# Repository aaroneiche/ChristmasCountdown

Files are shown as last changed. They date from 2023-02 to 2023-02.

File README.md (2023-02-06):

# Christmas Countdown

Christmas Countdown is a Christmas Ornament that counts down to Christmas day (or really any day) in Binary. Using two rows of LEDs, it displays the Days & Hours and then the Minutes & seconds remaining until Christmas Day. If you want to learn about how I approached developing it, and how many times I got it wrong, you can read my writeup of [the whole adventure here](https://aaroneiche.com/2023/02/05/christmas-countdown/) 



The heart of the circuit is an ESP32-C3-Mini-1. It drives fourteen SK6812 LEDs that display the time, as well as an indicator of the current mode. The time is kept by a PCF85363 with a battery backup . The ornament runs off of 5v, and requires about 1A with the LEDs running at full brightness (I do not recommend this, these LEDs will melt your face off) 

### Setting the time.

To set the ornament, press and hold the left button for 3 seconds and release. On the bottom row it shows what you're setting (year, month, day, hour, minute, second) and the top row displays the current value. There are 12 settings in all, 6 for the current date/time, and 6 for the target date/time. You can advance to the next value to set by pressing the left button. You can increase the value by pressing the right button. The value will return to zero (or one) after the maximum value has been reached. You do not need to do any math about timing, just set the current and target dates/times. The default target date is December 25th, 00:00:00 AM. You may wish to set the time to December 25th, 08:00:00 for when you start Christmas with your family. Perhaps you observe Orthodox Christmas and want to set it for January 7th.

When setting the current date/time, the whole bottom row will be lit with the value you're setting flashing on and off.
Here is an example of setting the current year (22 - for 2022)

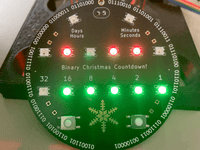
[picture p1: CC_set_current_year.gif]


When setting the target date/time, the whole bottom row will be off with the value you're setting flashing on an off.
Here is an example of setting the target month (12 - for December)

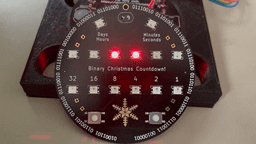
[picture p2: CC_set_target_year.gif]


When you've finished setting the values, press and hold the right button for 3 seconds. The countdown values will appear.

## Clock battery

If power is lost to Christmas Countdown, the RTC will go into battery mode automatically and will continue to count time. The RTC battery runs on very low power mode consuming ~320nA. 

If the battery is removed, some settings will be maintained on Christmas Countdown. The current time will need to be set again.

## Adding to the the software

I wrote most of this software in VSCode with PlatformIO. I programmed the Esp32-C3 using a CP1202 USB->UART adapter, and connecting the DTR and RTS pins. Alternatively, you should be able to put the board in download mode by holding down the "Program" button on the back while pressing and releasing the "Reset" button.

Changes to the firmware should be pretty easy to make. It's all (in)conveniently in a single file. A couple of helpful hints: 

A clock interrupt fires 1024 times a second. This is how the clock, and the various display updates are handled. There are currently events that execute at 1s, 0.5s and 0.25s. Any handler can be added to the `quarterSecondOverflow`, `halfSecondOverflow`, and `secondOverflow` branches in the loop. These are good locations for executing frequent.

The very last execution in the loop is to update the display. This creates a buffer and that is fed to the `displayFromBuffer` method. This should make it easy to set the display to whatever you want. To prevent your LEDs from getting overwritten by other stuff, make sure to pay attention to the other modes that are writing to the display. The easiest way to avoid this is to make your own Display Mode - you can add one about line 50 in the `enum DisplayMode`.

# Hardware

I typically order PCBs with 1oz copper, HASL Lead-Free. The Color isn't super important. I think that Black looks best, and if you're willing to splurge, Gold ENIG looks very nice on the Snowflake on the front.

The Piezo buzzer does not currently do anything. I have run some tests where I can get it to play some simple music. It definitely works, I just haven't done anything with it yet.

Taking advantage of the Interact HTML BOM, there's a component placement page included in this repo (`ibom.html`)

## What about Wifi?!?!

Yes, the onboard chip has support for Wifi. Which means that you could set the time automatically using NTP. And you could change settings on a webpage even! I have written some code to support these features, and when they're polished I will be making them available. For now, Christmas countdown must be programmed using a couple of buttons and your cunning.

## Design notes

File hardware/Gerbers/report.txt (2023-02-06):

Info: Front (top side) placement file: '/Users/aeiche/Documents/Personal/Electronics Projects/ChristmasCountdown2022_1.3/Gerbers/ChristmasCountdown2022-top.pos'.
Info: Component count: 21.
Info: Back (bottom side) placement file: '/Users/aeiche/Documents/Personal/Electronics Projects/ChristmasCountdown2022_1.3/Gerbers/ChristmasCountdown2022-bottom.pos'.
Info: Component count: 58.
Info: Full component count: 79.
Info: File generation successful.

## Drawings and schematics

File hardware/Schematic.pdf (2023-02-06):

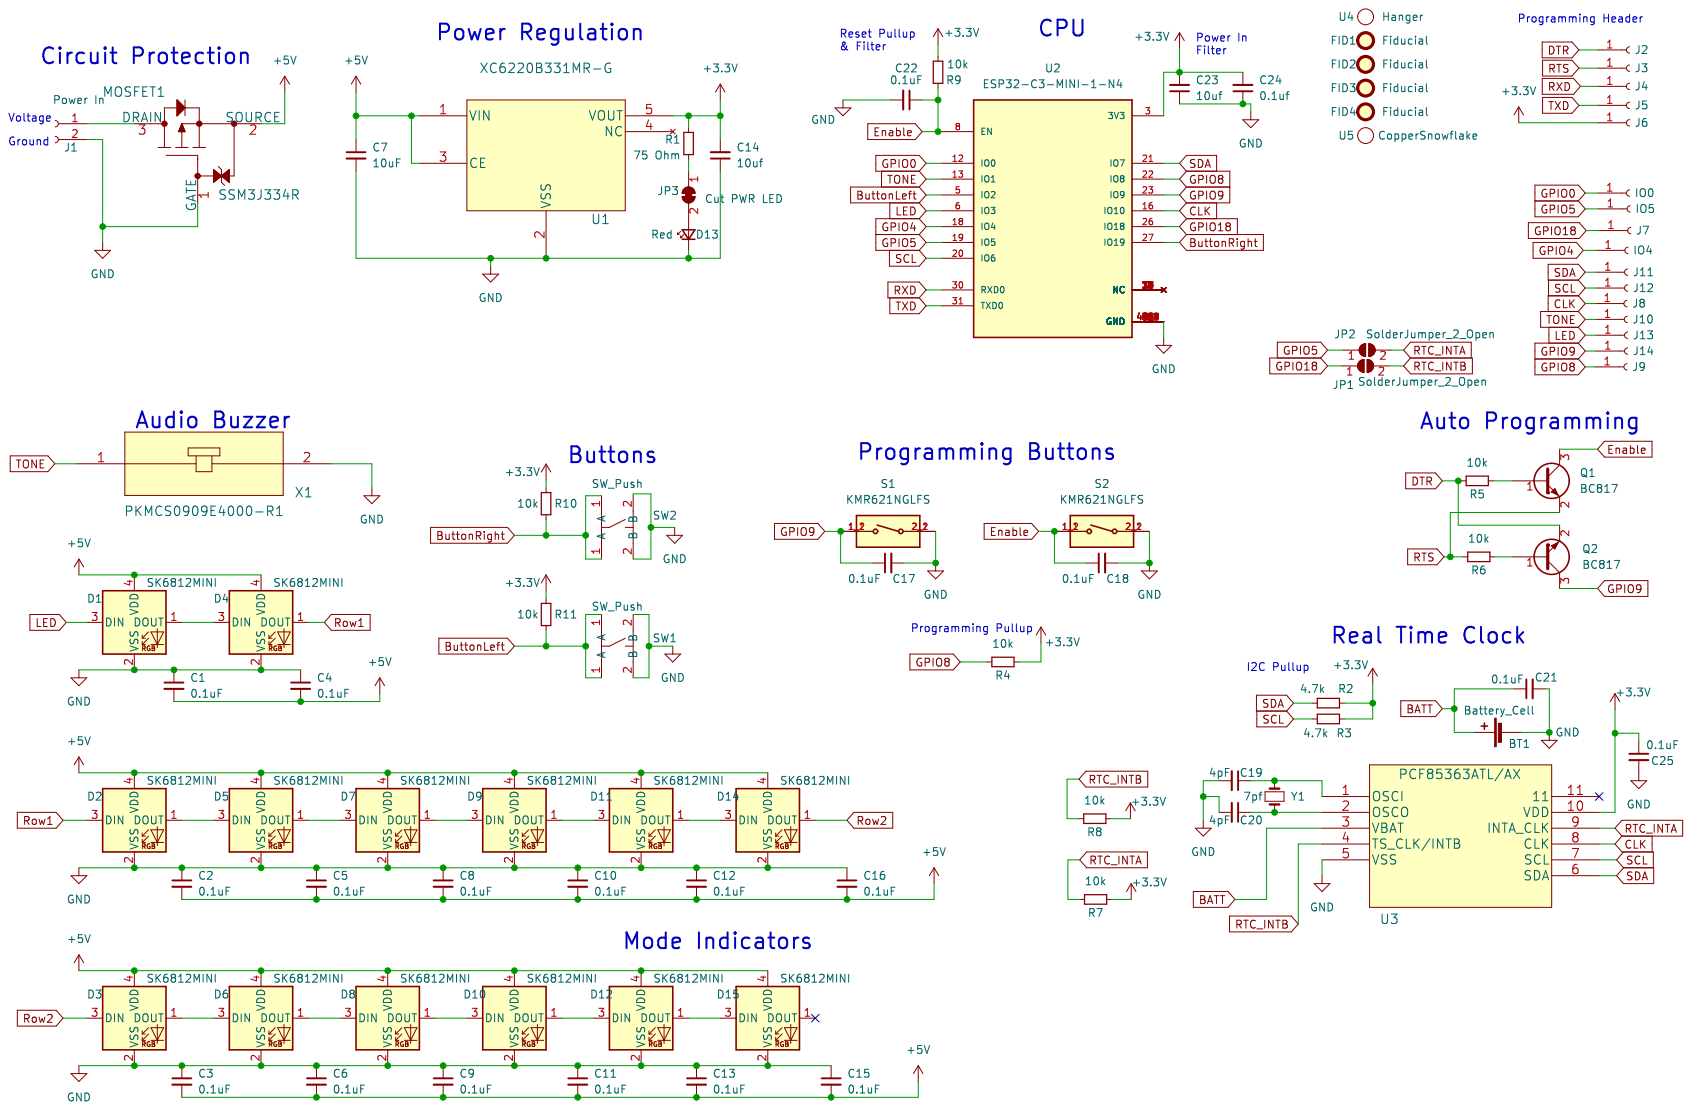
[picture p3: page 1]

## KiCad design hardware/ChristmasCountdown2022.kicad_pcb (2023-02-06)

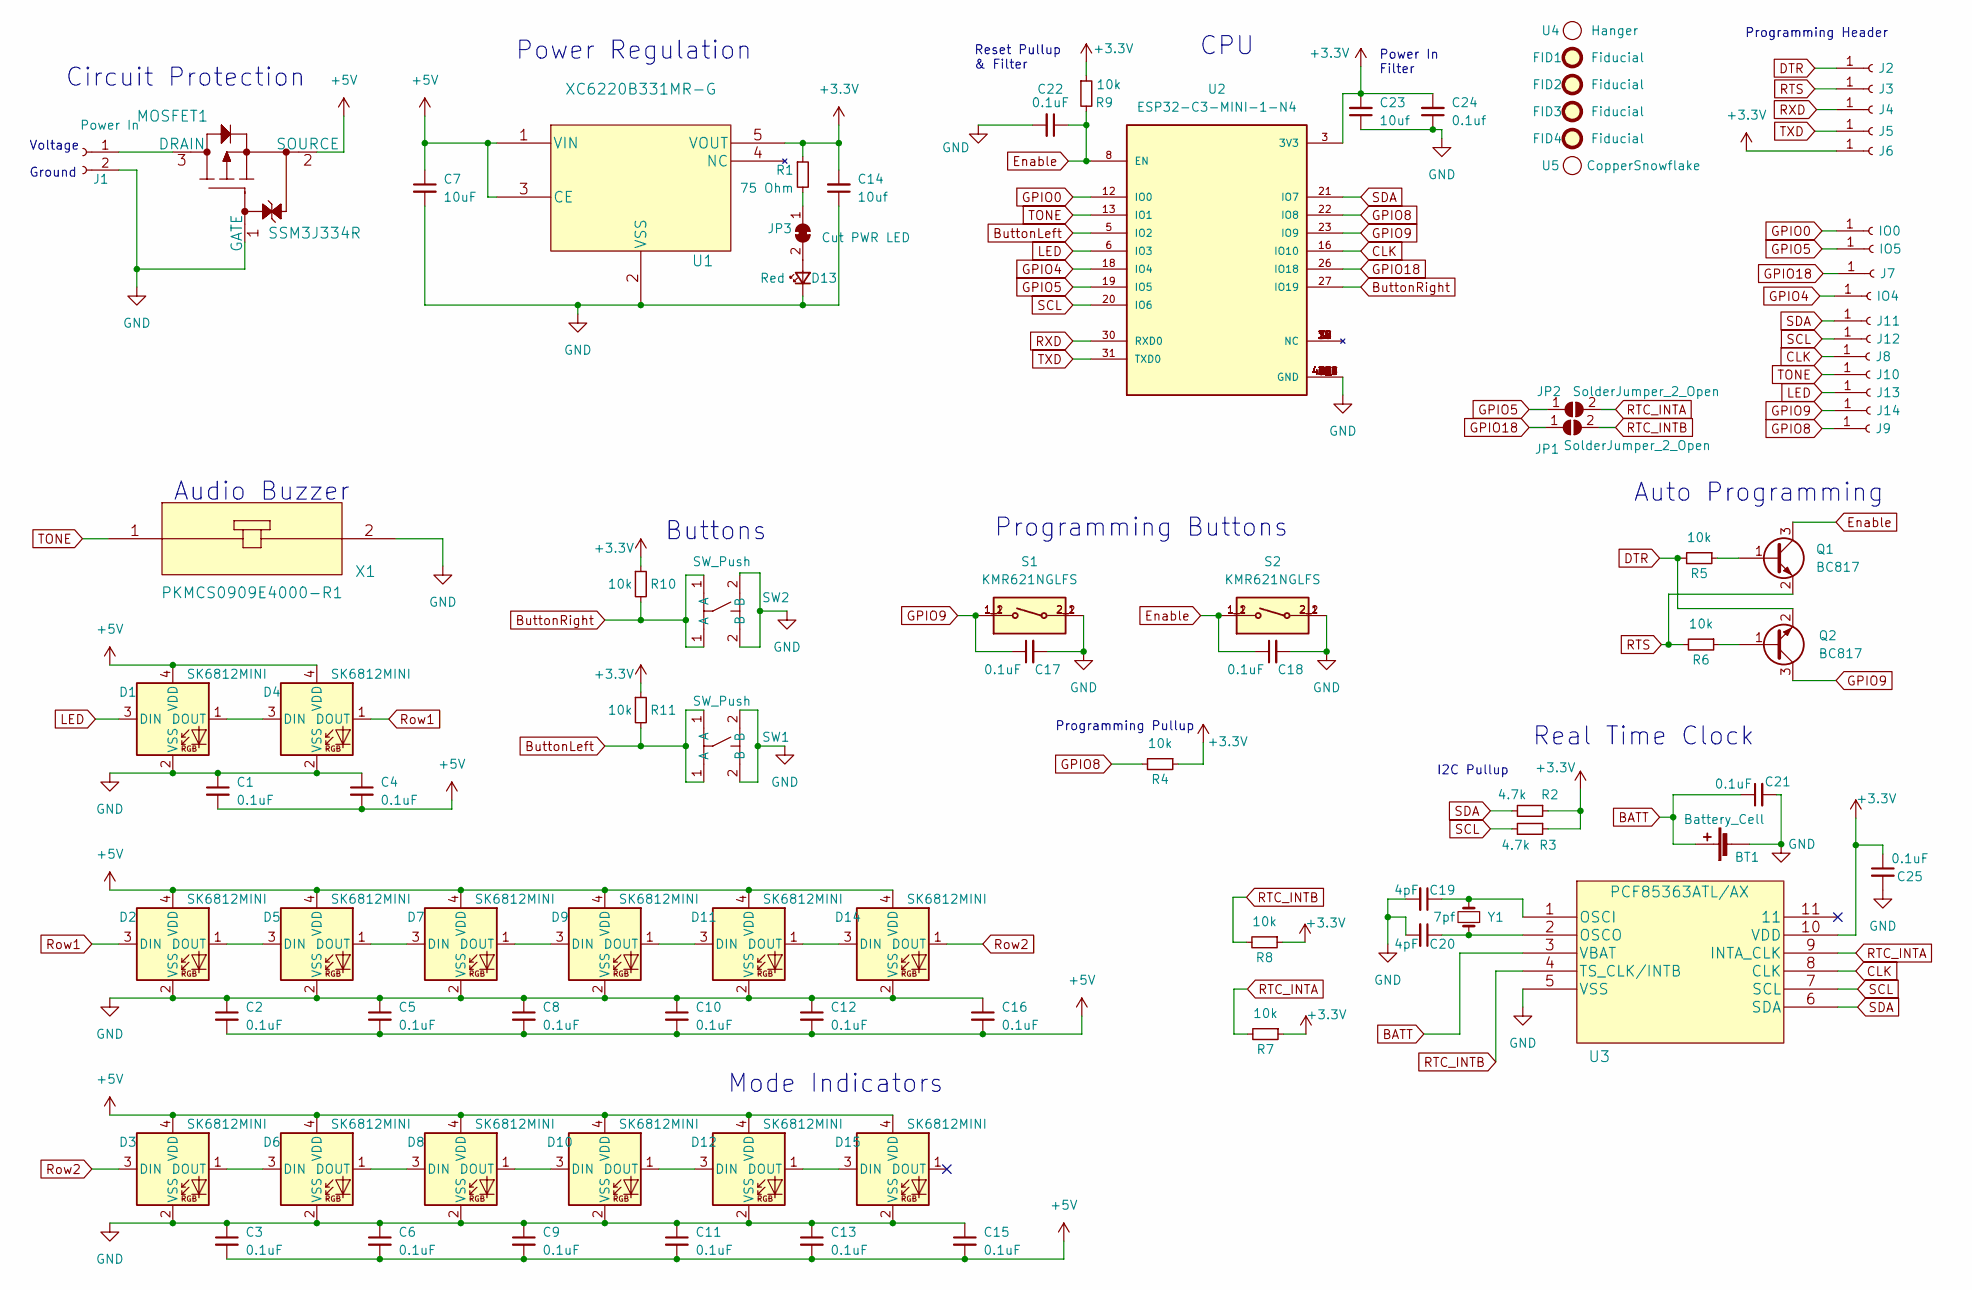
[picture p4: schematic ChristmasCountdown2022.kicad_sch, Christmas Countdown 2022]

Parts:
BT1: Battery_Cell; BatteryHolder_LINX_BAT-HLD-012-SMT
C1, C2, C3, C4, C5, C6, C8, C9, C10, C11, C12, C13, C15, C16, C17, C18, C21, C22, C25: 0.1uF; C_0805_2012Metric
C7: 10uF; C_0805_2012Metric
C14, C23: 10uf; C_0805_2012Metric
C19, C20: 4pF; R_0805_2012Metric
C24: 0.1uf; C_0805_2012Metric
D1, D2, D3, D4, D5, D6, D7, D8, D9, D10, D11, D12, D14, D15: SK6812MINI; LED_SK6812MINI_PLCC4_3.5x3.5mm_P1.75mm
D13: Red; LED_0805_2012Metric
FID1, FID2, FID3, FID4: Fiducial; Fiducial_0.5mm_Mask1mm
IO0: IO0; TestPoint_Pad_D2.0mm
IO4: IO4; TestPoint_Pad_D2.0mm
IO5: IO5; TestPoint_Pad_D2.0mm
J1: Power In; Hand_solderable_1x2
J2, J3, J4, J5, J6: Conn_01x01_Female; PinSocket_1x01_P2.54mm_Vertical
J7: IO18; TestPoint_Pad_D2.0mm
J8: CLK; PinSocket_1x01_P2.54mm_Vertical
J9: IO8; TestPoint_Pad_D2.0mm
J10: TONE; PinSocket_1x01_P2.54mm_Vertical
J11: SDA; TestPoint_Pad_D2.0mm
J12: SCL; TestPoint_Pad_D2.0mm
J13: LED; PinSocket_1x01_P2.54mm_Vertical
J14: IO9; TestPoint_Pad_D2.0mm
JP1, JP2: SolderJumper_2_Open; SolderJumper-2_P1.3mm_Open_RoundedPad1.0x1.5mm
JP3: Cut PWR LED; SolderJumper-2_P1.3mm_Bridged_RoundedPad1.0x1.5mm
MOSFET1: SSM3J334R
Q1, Q2: BC817; SOT-23
R1: 75 Ohm; R_0805_2012Metric
R2, R3: 4.7k; R_0805_2012Metric
R4, R5, R6, R7, R8, R9, R10, R11: 10k; R_0805_2012Metric
S1, S2: KMR621NGLFS; SW_KMR621NGLFS; PARTREV N/A
SW1, SW2: SW_Push; EVQQ2B03W; MFG_Part_number EVQ-Q2F02W
U1: XC6220B331MR-G
U2: ESP32-C3-MINI-1-N4; XCVR_ESP32-C3-MINI-1-N4; PARTREV v1.0
U3: PCF85363ATL/AX; PCF85363ATL_AX
U4: Hanger
U5: CopperSnowflake; CopperSnowflakeGraphic
X1: PKMCS0909E4000-R1
Y1: 7pf; CM8V-T1A-Crystal

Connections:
+3.3V: C14.2, C23.2, C24.2, C25.1, J6.1, R1.1, R2.1, R3.1, R4.1, R7.1, R8.1, R9.1, R10.1, R11.1, U1.5 (VOUT), U2.3 (3V3), U3.10 (VDD)
+5V: C1.2, C2.2, C3.2, C4.2, C5.2, C6.2, C7.1, C8.2, C9.2, C10.2, C11.2, C12.2, C13.2, C15.2, C16.2, D1.4 (VDD), D2.4 (VDD), D3.4 (VDD), D4.4 (VDD), D5.4 (VDD), D6.4 (VDD), D7.4 (VDD), D8.4 (VDD), D9.4 (VDD), D10.4 (VDD), D11.4 (VDD), D12.4 (VDD), D14.4 (VDD), D15.4 (VDD), MOSFET1.2 (SOURCE), U1.1 (VIN), U1.3 (CE)
BATT: BT1.1 (+), C21.1, U3.3 (VBAT)
ButtonLeft: R11.2, SW1.1 (A), U2.5 (IO2)
ButtonRight: R10.2, SW2.1 (A), U2.27 (IO19)
CLK: J8.1, U2.16 (IO10), U3.8 (CLK)
DTR: J2.1, Q2.2 (E), R5.2
Enable: C18.1, C22.1, Q1.3 (C), R9.2, S2.1_1, S2.1_2, U2.8 (EN)
GND: BT1.2 (-), C1.1, C2.1, C3.1, C4.1, C5.1, C6.1, C7.2, C8.1, C9.1, C10.1, C11.1, C12.1, C13.1, C14.1, C15.1, C16.1, C17.2, C18.2, C19.2, C20.2, C21.2, C22.2, C23.1, C24.1, C25.2, D1.2 (VSS), D2.2 (VSS), D3.2 (VSS), D4.2 (VSS), D5.2 (VSS), D6.2 (VSS), D7.2 (VSS), D8.2 (VSS), D9.2 (VSS), D10.2 (VSS), D11.2 (VSS), D12.2 (VSS), D13.1 (K), D14.2 (VSS), D15.2 (VSS), J1.2, MOSFET1.1 (GATE), S1.2_1, S1.2_2, S2.2_1, S2.2_2, SW1.2 (B), SW2.2 (B), U1.2 (VSS), U2.1 (GND), U2.2 (GND), U2.11 (GND), U2.14 (GND), U2.36 (GND), U2.37 (GND), U2.38 (GND), U2.39 (GND), U2.40 (GND), U2.41 (GND), U2.42 (GND), U2.43 (GND), U2.44 (GND), U2.45 (GND), U2.46 (GND), U2.47 (GND), U2.48 (GND), U2.49_1 (GND), U2.49_2 (GND), U2.49_3 (GND), U2.49_4 (GND), U2.49_5 (GND), U2.49_6 (GND), U2.49_7 (GND), U2.49_8 (GND), U2.49_9 (GND), U2.50 (GND), U2.51 (GND), U2.52 (GND), U2.53 (GND), U3.5 (VSS), X1.2
GPIO0: IO0.1, U2.12 (IO0)
GPIO4: IO4.1, U2.18 (IO4)
GPIO5: IO5.1, JP2.1 (A), U2.19 (IO5)
GPIO8: J9.1, R4.2, U2.22 (IO8)
GPIO9: C17.1, J14.1, Q2.3 (C), S1.1_1, S1.1_2, U2.23 (IO9)
GPIO18: J7.1, JP1.1 (A), U2.26 (IO18)
LED: D1.3 (DIN), J13.1, U2.6 (IO3)
unnamed: C19.1, U3.1 (OSCI), Y1.2
unnamed: C20.1, U3.2 (OSCO), Y1.1
unnamed: D1.1 (DOUT), D4.3 (DIN)
unnamed: D2.1 (DOUT), D5.3 (DIN)
unnamed: D3.1 (DOUT), D6.3 (DIN)
unnamed: D5.1 (DOUT), D7.3 (DIN)
unnamed: D6.1 (DOUT), D8.3 (DIN)
unnamed: D7.1 (DOUT), D9.3 (DIN)
unnamed: D10.1 (DOUT), D12.3 (DIN)
unnamed: D8.1 (DOUT), D10.3 (DIN)
unnamed: D11.1 (DOUT), D14.3 (DIN)
unnamed: D9.1 (DOUT), D11.3 (DIN)
unnamed: D12.1 (DOUT), D15.3 (DIN)
unnamed: D13.2 (A), JP3.2 (B)
unnamed: J1.1, MOSFET1.3 (DRAIN)
unnamed: JP3.1 (A), R1.2
unnamed: Q1.1 (B), R5.1
unnamed: Q2.1 (B), R6.1
RTC_INTA: JP2.2 (B), R7.2, U3.9 (INTA_CLK)
RTC_INTB: JP1.2 (B), R8.2, U3.4 (TS_CLK/INTB)
RTS: J3.1, Q1.2 (E), R6.2
RXD: J4.1, U2.30 (RXD0)
Row1: D2.3 (DIN), D4.1 (DOUT)
Row2: D3.3 (DIN), D14.1 (DOUT)
SCL: J12.1, R3.2, U2.20 (IO6), U3.7 (SCL)
SDA: J11.1, R2.2, U2.21 (IO7), U3.6 (SDA)
TONE: J10.1, U2.13 (IO1), X1.1
TXD: J5.1, U2.31 (TXD0)

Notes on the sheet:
Auto Programming
Circuit Protection
Power Regulation
CPU
Programming Header
Real Time Clock
Programming Pullup
Mode Indicators
Audio Buzzer
I2C Pullup
Buttons
Voltage
Power In Filter
Ground
Programming Buttons
Reset Pullup & Filter

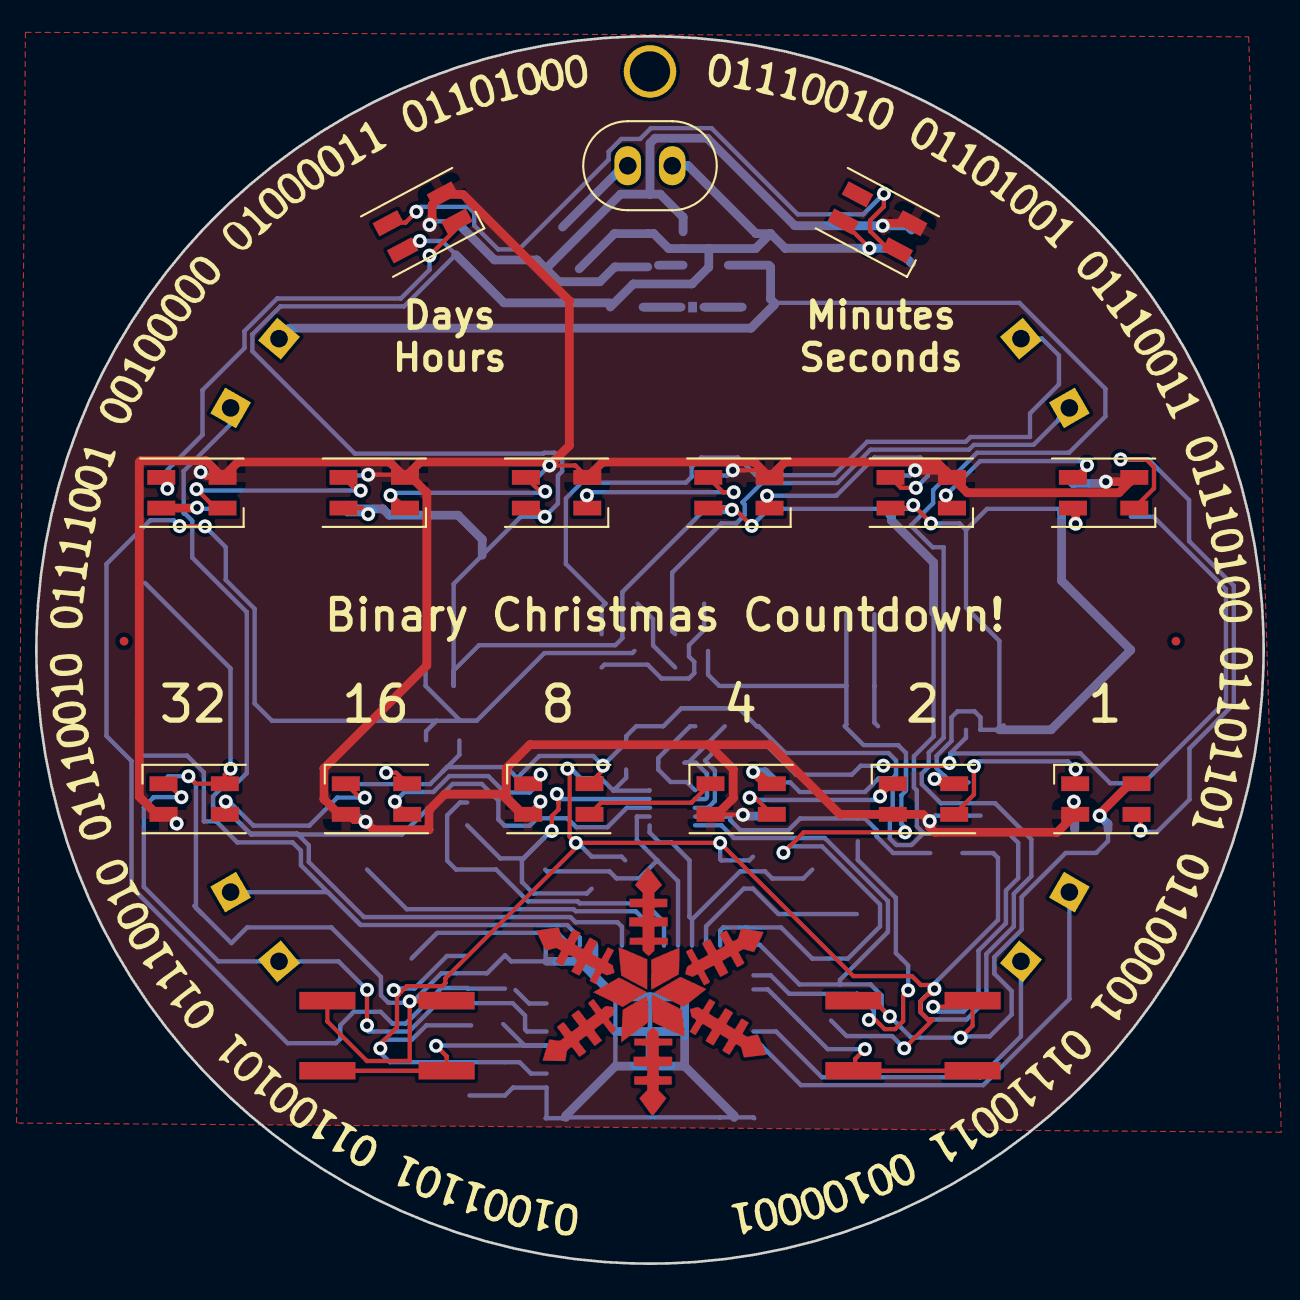
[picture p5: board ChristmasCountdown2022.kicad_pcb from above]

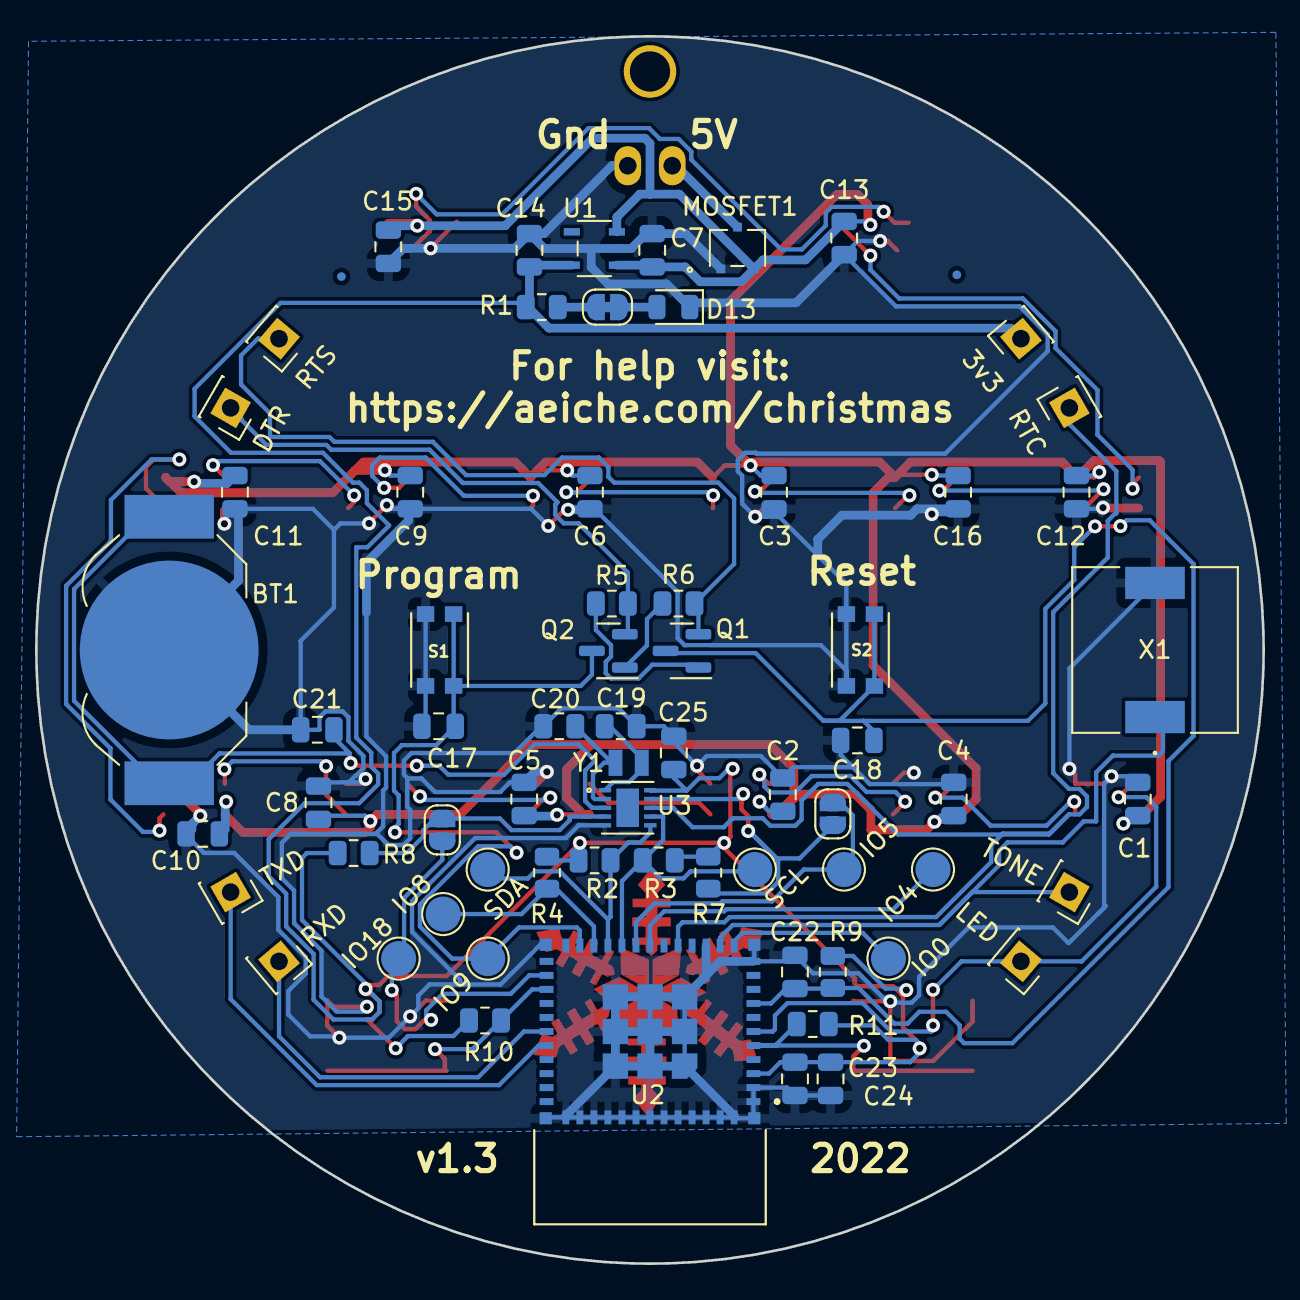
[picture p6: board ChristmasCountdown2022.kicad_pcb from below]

Board: 2 copper layers, 70.0 x 70.0 mm, 90 parts (69 on the bottom side), 44 nets.

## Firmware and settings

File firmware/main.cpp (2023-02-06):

#include <Arduino.h>
#include <Wire.h>
#include <Adafruit_NeoPixel.h>

#include <WiFi.h>

#include <WiFiUdp.h>
#include "NTP.h"

#include "credentials.h"
#include <Bounce2.h>

#include <TimeLib.h>

#include <Preferences.h>

// The I2C address of the RTC.
int address = 0x51;

// The structure that we manage a date in.
struct DateTime
{
  int month;
  int day;
  int hour;
  int minute;
  int second;
};

DateTime remaining;

int secondC = 0;
int halfSecondC = 0;
int quarterSecondC = 0;
int tenthSecondC = 0;

int completeDisplayCounter = 0;
int ledOffset = 0;

int secondOverflowCounter = 0;
int halfsecondOverflowCounter = 0;
int quarterSecondOverflowCounter = 0;

int leftButtonHeldCounter = 0;
int rightButtonHeldCounter = 0;

bool secondOverflow = false;
bool halfSecondOverflow = false;
bool quarterSecondOverflow = false;

//Debounce init.
Bounce bounceRight = Bounce();
Bounce bounceLeft = Bounce();

enum DisplayMode
{
  Day = 1,
  Minute = 2,
  Set = 3,
  Complete = 4
};

DisplayMode currentDisplayMode = Minute;

enum SettingValue
{
  SetDay = 1,
  SetHour = 2,
  SetMinute = 3,
  SetSecond = 4,
  SetMonth = 5,
  SetYear = 6,
  SetTargetDay = 7,
  SetTargetHour = 8,
  SetTargetMinute = 9,
  SetTargetSecond = 10,
  SetTargetMonth = 11,
  SetTargetYear = 12
};

SettingValue currentSettingValue = SetYear;

// counting occurs every 1/4 sec, so 48 * .25 = 12s between display modes.
int switchPeriod = 12;
int switchCounter = 0;

#define clockInputPin 5
#define rightButtonPin 19
#define leftButtonPin 2
#define LED_PIN 3

/*
Wifi Credentials are stored in a file called "credentials.h"
The contents of that should look like this:

#define WIFI_SSID "WifiNetworkName"
#define WIFI_PASSWORD "WifiPassword"

Make sure you don't commit this file into your repo.
*/
const char *ssid = WIFI_SSID;
const char *password = WIFI_PASSWORD;

Adafruit_NeoPixel leds(14, LED_PIN, NEO_GRB + NEO_KHZ800);

int timesInterruptCalled = 0;
bool updateDisplayFlag = false;
bool clockInterruptFlag = false;
bool leftPressedFlag = false;
bool rightPressedFlag = false;

bool clockRunning = false;
bool settingBlinkOn = false;

uint32_t dimRed = leds.Color(30, 0, 0);
uint32_t dimGreen = leds.Color(0, 30, 0);
uint32_t dimWhite = leds.Color(25, 25, 25);
uint32_t dimBlue = leds.Color(0, 0, 25);

uint32_t brightRed = leds.Color(255, 255, 255);
uint32_t brightGreen = leds.Color(255, 255, 255);
uint32_t brightWhite = leds.Color(255, 255, 255);

uint32_t off = leds.Color(0, 0, 0);

uint32_t displayBuffer[14];

tmElements_t tm;
tmElements_t ctm;
time_t targetDT;
time_t currentDT;

Preferences preferences;

WiFiUDP wifiUdp;
NTP ntp(wifiUdp);

uint8_t bcdToDec(uint8_t b)
{
  return (((b >> 4) * 10) + (b % 16));
}

byte decToBcd(byte b){
  Serial.print((b / 10 * 16) + (b % 10), HEX);
  return ( (b / 10 * 16) + (b % 10) );
}

/* RTC interactions */

tmElements_t readTimeFromRTC()
{
  Wire.beginTransmission(address);
  Wire.write((uint8_t)0x01); // Seconds Address
  Wire.endTransmission();

  tmElements_t timeReadOut;

  Wire.requestFrom(address, 7);
  timeReadOut.Second = bcdToDec(Wire.read() & 0x7f);
  timeReadOut.Minute = bcdToDec(Wire.read() & 0x7f);
  timeReadOut.Hour = bcdToDec(Wire.read() & 0x3f);
  
  timeReadOut.Day = bcdToDec(Wire.read() & 0xff);
  //Skip the day of the week.
  Wire.read();
  timeReadOut.Month = bcdToDec(Wire.read() & 0xff);
  timeReadOut.Year = bcdToDec(Wire.read() & 0xff);

  Wire.endTransmission();
  // currentDT = makeTime(ctm);
  return timeReadOut;
}

void writeTimeToRTC(tmElements_t time) {  

  Wire.beginTransmission(address);
  Wire.write((uint8_t)0x01); // Start register
  Wire.write(decToBcd(time.Second));
  Wire.write(decToBcd(time.Minute));
  Wire.write(decToBcd(time.Hour));

  Wire.write(decToBcd(time.Day));
  Wire.write(0); //We don't care about the day of the week.
  Wire.write(decToBcd(time.Month));
  Wire.write(decToBcd(time.Year));
  Wire.endTransmission();
}

void pauseRTC()
{
  Wire.beginTransmission(address);
  Wire.write((uint8_t)0x2e);
  Wire.write((uint8_t)0x01);
  Wire.endTransmission();
}

void unPauseRTC()
{
  Wire.beginTransmission(address);
  Wire.write((uint8_t)0x2e);
  Wire.write((uint8_t)0x00);
  Wire.endTransmission();
}


void readPreferences() {
  preferences.begin("prefs", false);
  preferences.getInt("target_year", -1);
  preferences.getInt("target_month", -1);
  preferences.getInt("target_day", -1);
  preferences.getInt("target_hour",-1);
  preferences.getInt("target_minute",-1);
  preferences.getInt("target_second",-1);

}

/* 
  A test function for reading from the RTC
  This prints out the current hour, minute and second.
*/
void clockTest()
{
  Wire.beginTransmission(address);
  Wire.write((uint8_t)0x01); // Seconds
  Wire.endTransmission();

  Wire.requestFrom(address, 7);
  int sec = bcdToDec(Wire.read() & 0x7f);
  int min = bcdToDec(Wire.read() & 0x7f);
  int hour = bcdToDec(Wire.read() & 0x3f);
  
  int day = bcdToDec(Wire.read() & 0x3f);
  Wire.read(); //read the day of week - don't care.
  int month = bcdToDec(Wire.read() & 0xf);
  int year = bcdToDec(Wire.read() & 0xff);
  
  Wire.endTransmission();

  Serial.printf("%i/%i/%i %i:%i:%i\n",year-30, month, day, hour, min, sec);
}

/* Sets remaining vars to remaining time. return true is target is met,
or false if time remains */
bool utToRemaining(time_t &current, time_t &target)
{
  long diff = target - current;
  if (diff < 0)
  {
    // If we're at or have surpassed the target
    //  return;
    return true;
  }

  int days = floor(int(diff / 86400));
  long diffHours = diff - (86400 * days);
  int hours = floor(int(diffHours / 3600));
  long diffMin = diffHours - (3600 * hours);
  int minutes = floor(int(diffMin / 60));
  int seconds = diffMin - (60 * minutes);

  // Update our "remaining" values. These are used in the display.
  remaining.day = days;
  remaining.hour = hours;
  remaining.minute = minutes;
  remaining.second = seconds;
  return false;
}

void IRAM_ATTR clockInterrupt()
{
  clockInterruptFlag = true;
}

void setup()
{

  // Buttons have hardware pullups, so no need to set them here.
  bounceLeft.attach(leftButtonPin, INPUT);
  bounceRight.attach(rightButtonPin, INPUT);

  // This line is important for if you need to use pin18 or 19 internal pullups.
  //  CLEAR_PERI_REG_MASK(USB_SERIAL_JTAG_CONF0_REG, USB_SERIAL_JTAG_DP_PULLUP);

  leds.begin();           // INITIALIZE NeoPixel leds object (REQUIRED)
  leds.show();            // Turn OFF all pixels ASAP
  leds.setBrightness(50); // Set BRIGHTNESS to about 1/5 (max = 255)

  // Serial output for debug and info.
  Serial.begin(115200);
  Serial.println("ChristmasCountdown, Started up.");


  // Startup comms with the RTC.
  Wire.begin(7, 6);

  tmElements_t time = readTimeFromRTC();
  Serial.printf("Time read from RTC: %i/%i/%i %i:%i:%i", time.Year, time.Month, time.Day, time.Hour, time.Minute, time.Second);
  //We really only need to know if the year is 0, if so, the clock is not set.
  if(time.Year == 0) {
    //Clock not set. Set defaults, setup clock. 

    //Default RTC settings
    Wire.beginTransmission(address);
    Wire.write((uint8_t)0x23); // Start register
    Wire.write((uint8_t)0x00); // 0x23
    Wire.write((uint8_t)0x00); // 0x24 Two's complement offset value
    Wire.write((uint8_t)0x00); // 0x25 Normal offset correction, enable low-jitter mode, set load caps to 7.0pF
    Wire.write((uint8_t)0x00); // 0x26 Battery switch reg, same as after a reset
    Wire.write((uint8_t)0x00); // 0x27 Enable CLK pin, using bits set in reg 0x28
    Wire.write((uint8_t)0x45); // 0x28 Realtime clock mode, periodic interrupts, CLK pin generates 1024hz signal
    Wire.write((uint8_t)0x40); // 0x29
    Wire.write((uint8_t)0x00); // 0x2a
    Wire.endTransmission();

    // create a default current time (2022/12/01 0:0:0)
    tmElements_t defaults;
    defaults.Year = 52;
    defaults.Month = 12;
    defaults.Day = 1;
    defaults.Hour = 0;
    defaults.Minute = 0;
    defaults.Second = 0;
    
    writeTimeToRTC(defaults);

    //Read the time from the RTC.
    time = readTimeFromRTC();
    
    //Just to confirm our updated time. 
    Serial.printf("Time set to: %i/%i/%i %i:%i:%i", time.Year, time.Month, time.Day, time.Hour, time.Minute, time.Second);
  }else{
    time = readTimeFromRTC();
  }
  currentDT = makeTime(time);

  //Read target time from preferences. 

  //Set default time TEMPORARY - this should be from preferences.
  tm.Day = 25;
  tm.Hour = 0;
  tm.Minute = 0;
  tm.Second = 0;
  tm.Month = 12;
  tm.Year = 52;

  targetDT = makeTime(tm);


  Serial.print("The target: ");
  Serial.println(targetDT);
  Serial.print("Current: ");
  Serial.println(currentDT);
  
  //The last thing we'll do on setup is enable the clock interrupt pin, so we can start counting.
  pinMode(clockInputPin, INPUT_PULLUP);
  attachInterrupt(clockInputPin, clockInterrupt, FALLING);
}
unsigned long last = 0;

/*
 This abstracts away writing to the display from the actual contents of it.
 To turn LEDS on, generate a uint32_t array of colors, and pass it to this.
*/
void displayFromBuffer(uint32_t *dataBuffer)
{
  leds.clear();
  for (int i = 0; i < 14; i++)
  {
    // Serial.printf("this: %p", dataBuffer[i]);
    leds.setPixelColor(i, dataBuffer[i]);
  }
  leds.show();
}

void clearBuffer(uint32_t *dataBuffer)
{
  for (int i = 0; i < 14; i++)
  {
    dataBuffer[i] = off;
  }
}

void setTopRow(int value, uint32_t buffer[])
{
  for (int i = 0; i < 6; i++)
  {
    if ((value & (1 << i)) > 0)
    {
      // Set the LED - offset i by 6 because we're 6 LEDs into the strand
      buffer[i + 6] = dimRed;
    }
  }
}

void setBottomRow(int value, uint32_t buffer[])
{
  for (int i = 5; i >= 0; i--)
  {
    if ((value & (1 << i)) > 0)
    {
      buffer[abs(i - 5)] = dimGreen;
    }
  }
}

/*
  Sets the provided buffer to the current remaining time, targetDT and currentDT.
*/
void timeRemainingToBuffer(uint32_t buffer[])
{
  clearBuffer(buffer);
  int topVal = (currentDisplayMode == Day) ? remaining.day : remaining.minute;
  int bottomVal = (currentDisplayMode == Day) ? remaining.hour : remaining.second;

  if (currentDisplayMode == Day)
  {
    buffer[12] = dimWhite;
  }
  else if (currentDisplayMode == Minute)
  {
    buffer[13] = dimWhite;
  }

  setTopRow(topVal, buffer);
  setBottomRow(bottomVal, buffer);
}

/* 
 Writes the "set time" displays to the buffer. 
*/
void settingTimeToBuffer(uint32_t buffer[])
{
  clearBuffer(buffer);
  Serial.printf("Setting val: %i", currentSettingValue);
  switch (currentSettingValue)
  {
  case SetDay:
    if (settingBlinkOn == true)
    {
      setBottomRow(55, buffer);
    }
    else
    {
      setBottomRow(63, buffer);
    }
    setTopRow(ctm.Day, buffer);
    break;
  case SetHour:
    if (settingBlinkOn == true)
    {
      setBottomRow(59, buffer);
    }
    else
    {
      setBottomRow(63, buffer);
    }
    setTopRow(ctm.Hour, buffer);
    break;
  case SetMinute:
    if (settingBlinkOn == true)
    {
      setBottomRow(61, buffer);
    }
    else
    {
      setBottomRow(63, buffer);
    }
    setTopRow(ctm.Minute, buffer);
    break;
  case SetSecond:
    if (settingBlinkOn == true)
    {
      setBottomRow(62, buffer);
    }
    else
    {
      setBottomRow(63, buffer);
    }
    setTopRow(ctm.Second, buffer);
    break;
  case SetMonth:
    if (settingBlinkOn == true)
    {
      setBottomRow(47, buffer);
    }
    else
    {
      setBottomRow(63, buffer);
    }
    setTopRow(ctm.Month, buffer);
    break;
  case SetYear:
    if (settingBlinkOn == true)
    {
      setBottomRow(31, buffer);
    }
    else
    {
      setBottomRow(63, buffer);
    }
    setTopRow(ctm.Year - 30, buffer);
    break;
  case SetTargetDay:
    if (settingBlinkOn == true)
    {
      setBottomRow(8, buffer);
    }
    else
    {
      setBottomRow(0, buffer);
    }
    setTopRow(tm.Day, buffer);
    break;
  case SetTargetHour:
    if (settingBlinkOn == true)
    {
      setBottomRow(4, buffer);
    }
    else
    {
      setBottomRow(0, buffer);
    }
    setTopRow(tm.Hour, buffer);
    break;
  case SetTargetMinute:
    if (settingBlinkOn == true)
    {
      setBottomRow(2, buffer);
    }
    else
    {
      setBottomRow(0, buffer);
    }
    setTopRow(tm.Minute, buffer);
    break;
  case SetTargetSecond:
    if (settingBlinkOn == true)
    {
      setBottomRow(1, buffer);
    }
    else
    {
      setBottomRow(0, buffer);
    }
    setTopRow(tm.Second, buffer);
    break;
  case SetTargetMonth:
    if (settingBlinkOn == true)
    {
      setBottomRow(16, buffer);
    }
    else
    {
      setBottomRow(0, buffer);
    }
    setTopRow(tm.Month, buffer);
    break;
  case SetTargetYear:
    if (settingBlinkOn == true)
    {
      setBottomRow(32, buffer);
    }
    else
    {
      setBottomRow(0, buffer);
    }
    setTopRow(tm.Year - 30, buffer);
    break;
  }
}


void ledChaseToBuffer(uint32_t color, uint32_t *dataBuffer, int offset)
{
  clearBuffer(dataBuffer);

  // For each 3rd pixel, display it at this color:
  for (int l = offset; l <= 13; l = l + 3)
  {
     dataBuffer[l] = color;
  }
}

void printTime()
{
  // Serial.printf("%i/%i %i:%i:%i\n", current.month, current.day, current.hour, current.minute, current.second);
  Serial.printf("Remaining: %i days %i:%i:%i\n", remaining.day, remaining.hour, remaining.minute, remaining.second);
}

void leftPressedChange() {

  if(currentDisplayMode == Minute) {
    currentDisplayMode = Day;
  }else if(currentDisplayMode == Day) {
    currentDisplayMode = Minute;
  }

  //Temporary testing
  if(currentDisplayMode == Complete) {
    currentDisplayMode = Minute;
  }


  if (currentDisplayMode == Set) {

    /* Set Current Values */
    if (currentSettingValue == SetYear)
    {
      currentSettingValue = SetMonth;
    }
    else if (currentSettingValue == SetMonth)
    {
      currentSettingValue = SetDay;
    }
    else if (currentSettingValue == SetDay)
    {
      currentSettingValue = SetHour;
    }
    else if (currentSettingValue == SetHour)
    {
      currentSettingValue = SetMinute;
    }
    else if (currentSettingValue == SetMinute)
    {
      currentSettingValue = SetSecond;
    }
    /* Set Target Values */

    else if(currentSettingValue == SetSecond)
    {
      currentSettingValue = SetTargetYear;
    }
    else if (currentSettingValue == SetTargetYear)
    {
      currentSettingValue = SetTargetMonth;
    }
    else if (currentSettingValue == SetTargetMonth)
    {
      currentSettingValue = SetTargetDay;
    }
    else if (currentSettingValue == SetTargetDay)
    {
      currentSettingValue = SetTargetHour;
    }
    else if (currentSettingValue == SetTargetHour)
    {
      currentSettingValue = SetTargetMinute;
    }
    else if (currentSettingValue == SetTargetMinute)
    {
      currentSettingValue = SetTargetSecond;
    } 
    else if (currentSettingValue == SetTargetSecond) 
    {
      currentSettingValue = SetYear;
    }
    Serial.printf("Current Setting value: %i",currentSettingValue);
  }
}
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
void loop()
{
  // Update the button states
  bounceRight.update();
  bounceLeft.update();

  // If the right button has changed...
  if (bounceRight.changed())
  {
    int debouncedRight = bounceRight.read();
    // LOW is active.
    if (debouncedRight == false)
    {
      rightPressedChange();
      rightPressedFlag = true;
      Serial.println("Right Pressed");
      updateDisplayFlag = true;
    }
    else
    {
      // If changed to LOW, do this
      Serial.println("Right Released");
      rightPressedFlag = false;
      rightButtonHeldCounter = 0;
    }
  }

  // If the left button has changed...
  if (bounceLeft.changed())
  {

    int debouncedLeft = bounceLeft.read();
    // LOW is active.
    if (debouncedLeft == false)
    {
      Serial.println("Left pressed");
      leftPressedFlag = true;
      leftPressedChange();
      updateDisplayFlag = true;
    }
    else
    {
      Serial.println("Left Released");
      leftPressedFlag = false;
      leftButtonHeldCounter = 0;
    }
  }

  // The Clock interrupt is responsible to making sure events are triggered.
  // The RTC clock pin is configured to fire 1024 times a second. It triggers according to 
  // time divisions. 1024 is 1 second. 512 is 0.5 seconds. Counters will increment, and 
  // overflow when they hit the appropriate number. This is also a good place to 
  // time how long and event has occurred (such as a button press)
  if (clockInterruptFlag)
  {
    secondOverflowCounter++;
    halfsecondOverflowCounter++;
    quarterSecondOverflowCounter++;

    // Second overflow count. RTC runs at 1024/s
    if (secondOverflowCounter > 1024)
    {
      secondOverflow = true;
      secondOverflowCounter = 0;
      switchCounter++;
    }

    if (leftPressedFlag)
    {
      leftButtonHeldCounter++;
      if (leftButtonHeldCounter >= 3072)
      {
        if (currentDisplayMode == Minute || currentDisplayMode == Day || currentDisplayMode == Complete)
        {
          currentDisplayMode = Set;
          leftButtonHeldCounter = 0;
          //pause RTC
          pauseRTC();

          ctm = readTimeFromRTC();
          currentDT = makeTime(ctm);
          
          settingBlinkOn = true;
          updateDisplayFlag = true;
        }
        else
        {
          // Update the countdown value with the newly set time 
          // If you haven't changed the time, then it will set it to whatever the current time is.

          //Set the TargetDT to the new (or unchanged) value.
          targetDT = makeTime(tm);

          //Make sure we pause the RTC before updating the time. 
          pauseRTC();

          //Write time to RTC
          writeTimeToRTC(ctm);

          //Unpause after we've written;
          unPauseRTC();

          //Get the time from the RTC, set the currentDT
          ctm = readTimeFromRTC();
          currentDT = makeTime(ctm);

          currentDisplayMode = Minute;
          leftButtonHeldCounter = 0;
        }
      }
    }

    /* Currently I don't have anything running on the right button 3s hold.  */
    if (rightPressedFlag)
    {
      rightButtonHeldCounter++;
      if (rightButtonHeldCounter >= 3072)
      {
        // Serial.println("held right button for 3+ seconds.");
      }
    }

    if (halfsecondOverflowCounter > 512)
    {
      halfSecondOverflow = true;
      halfsecondOverflowCounter = 0;
    }

    if (quarterSecondOverflowCounter > 256)
    {
      quarterSecondOverflow = true;
      quarterSecondOverflowCounter = 0;
    }

    //Clear the flag once we've done everything associated with it.
    clockInterruptFlag = false;
  }

  if (quarterSecondOverflow) {
    if (currentDisplayMode == Complete)
    {
      // Sequence through the day mode complete methods
      ledOffset++;
      if (ledOffset > 2)
      {
        ledOffset = 0;
      }
      completeDisplayCounter = (completeDisplayCounter >= 12) ? 0 : completeDisplayCounter + 1;
      updateDisplayFlag = true;
    }

    quarterSecondOverflow = false;
  }

  if (halfSecondOverflow)
  {

    /* If we're setting the time, toggle the settingBlinkOn to create blinking. */
    if (currentDisplayMode == Set)
    {
      settingBlinkOn = !settingBlinkOn;
      updateDisplayFlag = true;
    }

    halfSecondOverflow = false;
  }

  if (secondOverflow)
  {

    if (currentDisplayMode == Minute || currentDisplayMode == Day)
    {
      // Add one to currentDT.
      currentDT++;

      if(switchCounter == switchPeriod) {
        switchCounter = 0;
        //Switch the display every n seconds automatically.
        currentDisplayMode = (currentDisplayMode == Minute) ? Day : Minute;
      }

      // Check for complete countdown.
      bool complete = utToRemaining(currentDT, targetDT);

      if (complete)
      {
        currentDisplayMode = Complete;
      }

      updateDisplayFlag = true;
      secondOverflow = false;
    }
  }

  // Any of the above methods might set the updateDisplayFlag.
  // Update display should always be the last thing that happens.
  if (updateDisplayFlag)
  {

    if(currentDisplayMode == Complete) {
      ledChaseToBuffer(dimRed, displayBuffer, ledOffset);
    }

    if (currentDisplayMode == Minute || currentDisplayMode == Day)
    {
      timeRemainingToBuffer(displayBuffer);
    }

    if (currentDisplayMode == Set)
    {
      settingTimeToBuffer(displayBuffer);
    }

    displayFromBuffer(displayBuffer);
    updateDisplayFlag = false;
  }
}

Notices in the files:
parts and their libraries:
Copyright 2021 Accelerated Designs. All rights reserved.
